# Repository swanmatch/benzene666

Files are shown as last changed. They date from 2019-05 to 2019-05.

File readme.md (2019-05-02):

# benzene666ビルドガイド

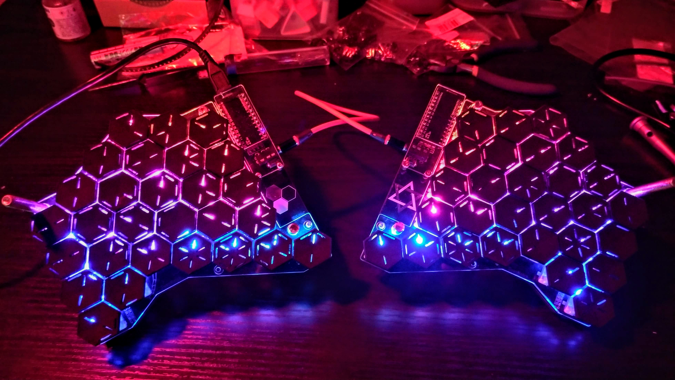
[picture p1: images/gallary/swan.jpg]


## 材料

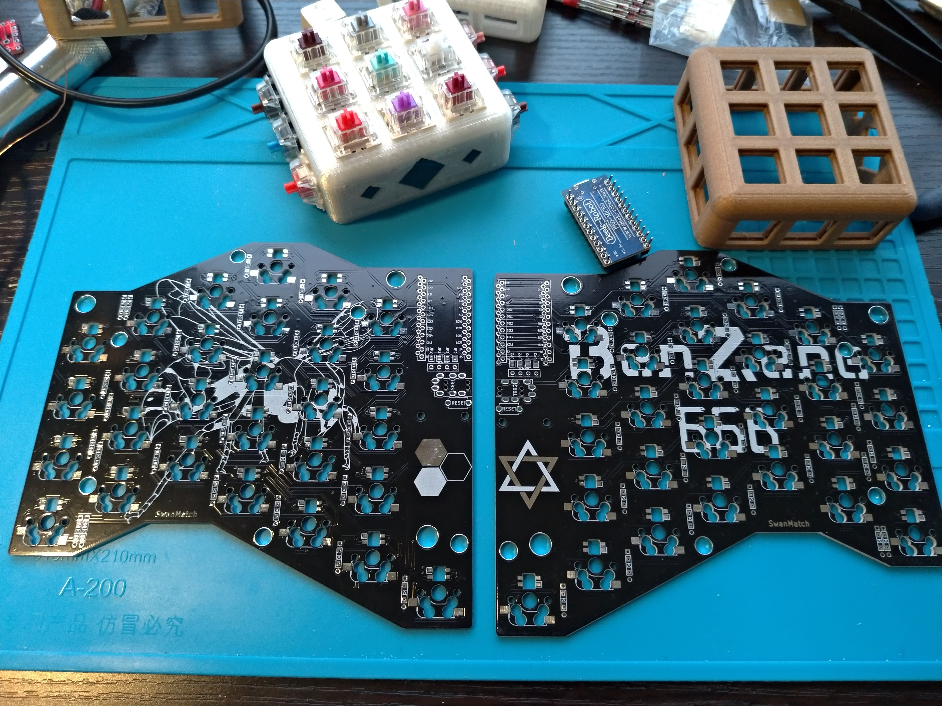
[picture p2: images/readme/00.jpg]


### キットに含まれるもの

| 品目 | 数量 |
| --- | ---- |
| PCB | 2枚  |
| トッププレート | 2枚  |
| ボトムプレート | 2枚  |
| OLED保護プレート | 2枚  |
| ProMicro | 2個  |
| ダイオード | 56個 |
| LED | 56個 |
| Kailhソケット | 56個 |
| M24mmネジ | 28本 |
| 7mm六角スペーサ  | 12本 |
| 8mm丸スペーサ | 4本  |
| 低頭ネジ | 4本  |
| ゴム足 | 10本 |

### キット以外で必要なもの
| 品目 | 数量 |
| --- | ---- |
| スイッチ | 56個 |
| キーキャップ | 56個 |
| TRRSまたはTRSケーブル | 1本  |
| USBケーブル | 1本  |

### オプション品

| 品目 | 数量 |
| --- | ---- |
| コンスルー | 4本  |
| M6ボルト | 6本  |
| M6ナット | 6個  |
| *)OLED | 2個  |

OLEDは動作未検証です。

## 組み立て手順

### LED

LEDをはんだ付けします。

シルクで白く囲ってあるのが一番大きいパッドです。

温度調整はんだごてで220度くらいに設定してください。もたついてると壊れます。

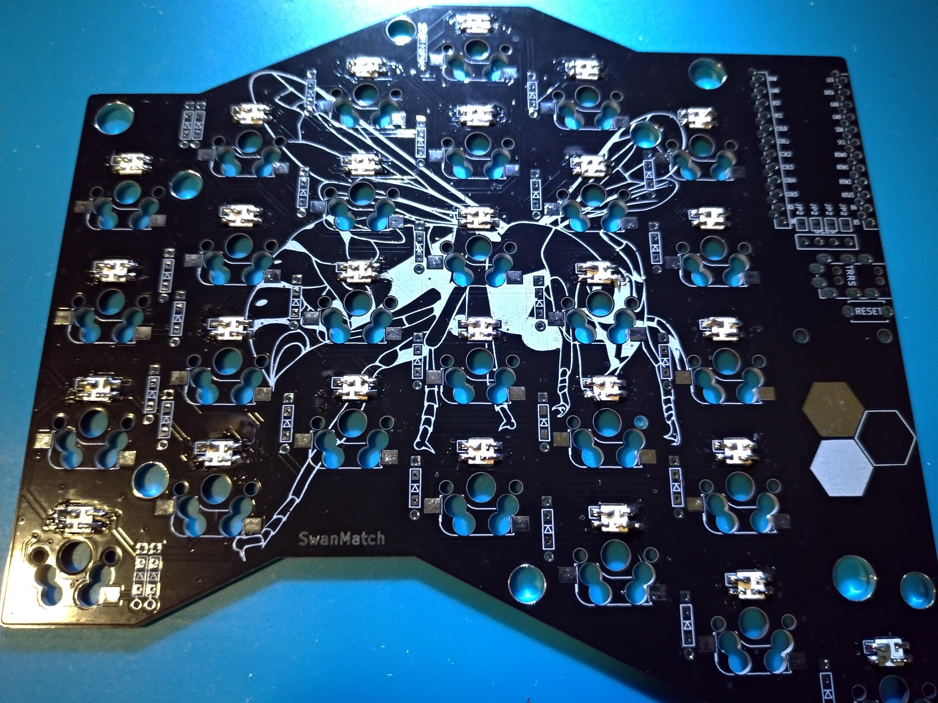
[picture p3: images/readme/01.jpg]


### ダイオード

ダイオードをはんだ付けしてください。向きに気をつけてください。

スルーホールの場合は黒が上、表面実装の場合うっすら線が書いてあるほうが上です。

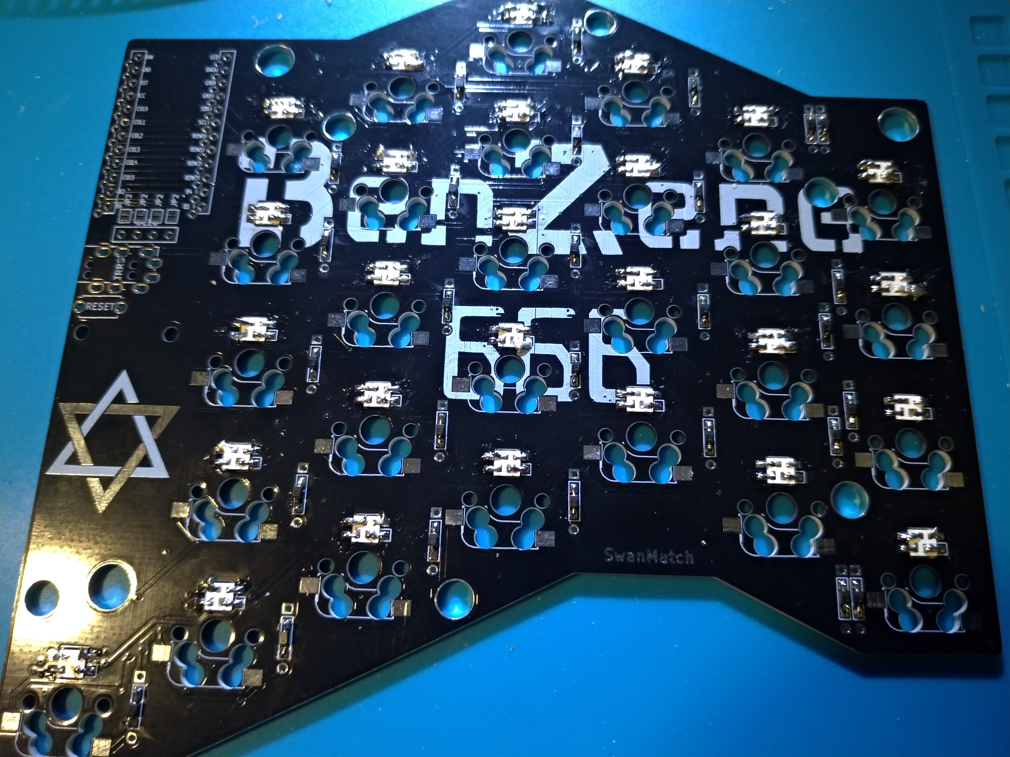
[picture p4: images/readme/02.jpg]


### ソケット

ソケットをはんだ付けしてください。

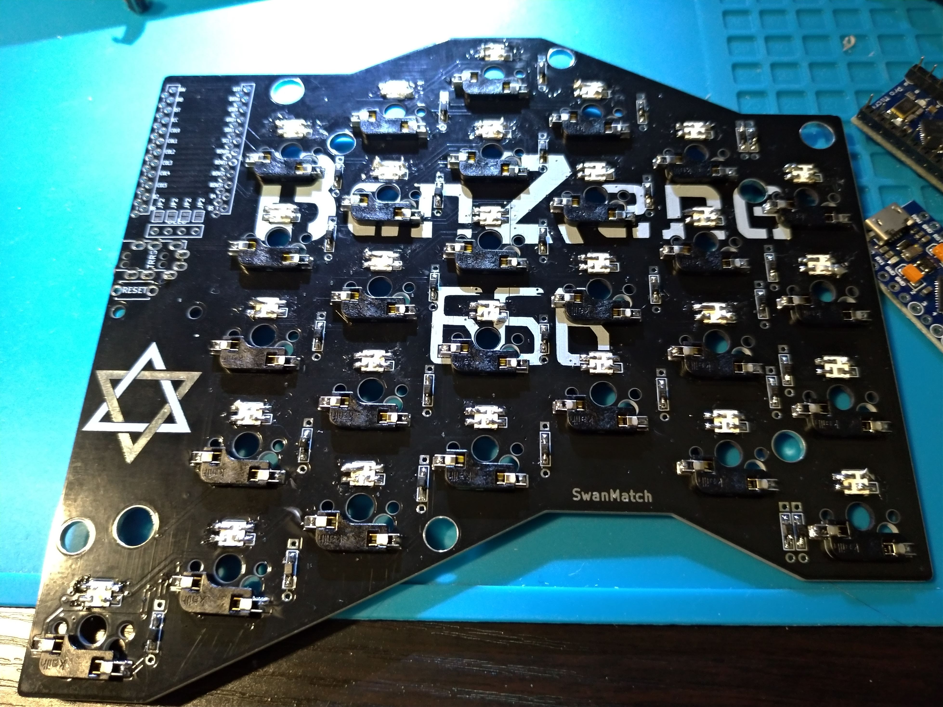
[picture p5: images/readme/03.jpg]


### TRRS、リセットスイッチ

はんだ付けしてください。

### ProMicro

ここだけは間違えるとリカバリが面倒なので、細心の注意をして作業にあたってください。

コンスルーを使う場合はHelixなどのビルドガイドを参考にしてください。

四角く囲ってあるところに付属のピンを指して裏からはんだ付けして、表面にProMicroを指してはんだ付けしてください。

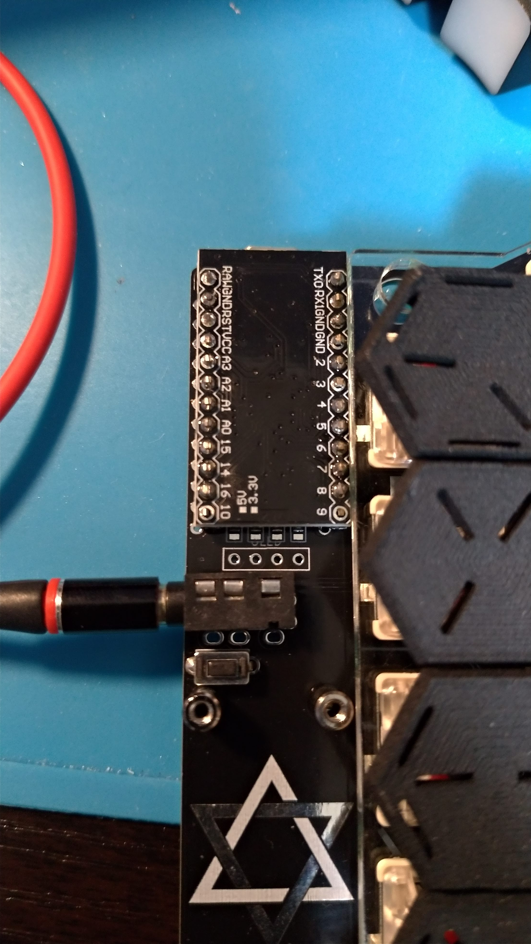
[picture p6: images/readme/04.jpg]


### スイッチ

トッププレートにスイッチをはめて、PCBに刺します。

このときすべてのピンが真っすぐになっていることを確認してください。

ピンが折れてしまいます。

### OLED保護プレート

PCB裏側から丸スペーサーをネジ止めして、表側に保護プレートを挟み込む形で低頭ネジでとめます。

### プレート

六角スペーサーとネジでPCBをサンドします。

ボトムプレートにゴム足を貼り付けてください。

反対側も同様に組み立てます。

### ファームウェア

```sh
git clone https://github.com/swanmatch/qmk_firmware.git
cd qmk_firmware
make benzene:swan:avrdude
```

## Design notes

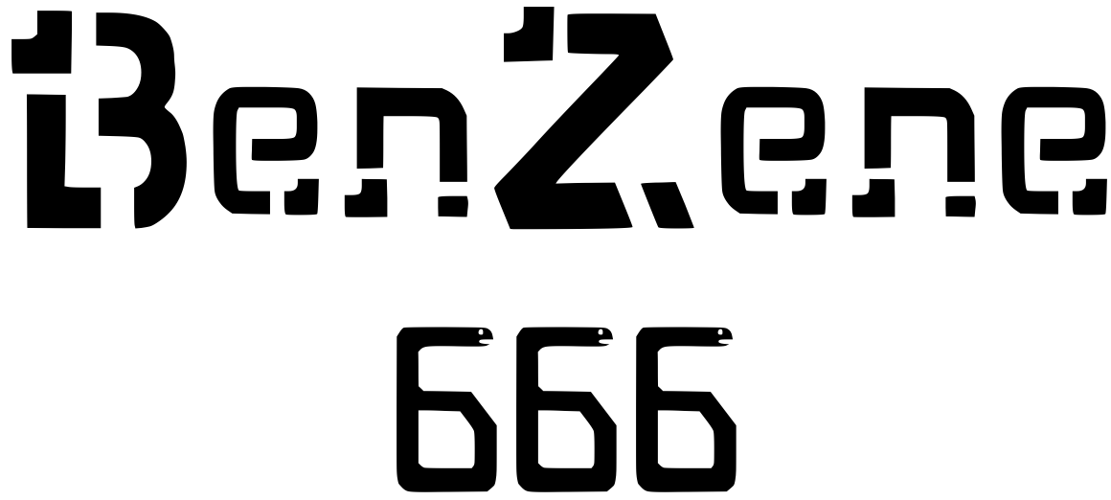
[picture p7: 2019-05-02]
case/benzene.png

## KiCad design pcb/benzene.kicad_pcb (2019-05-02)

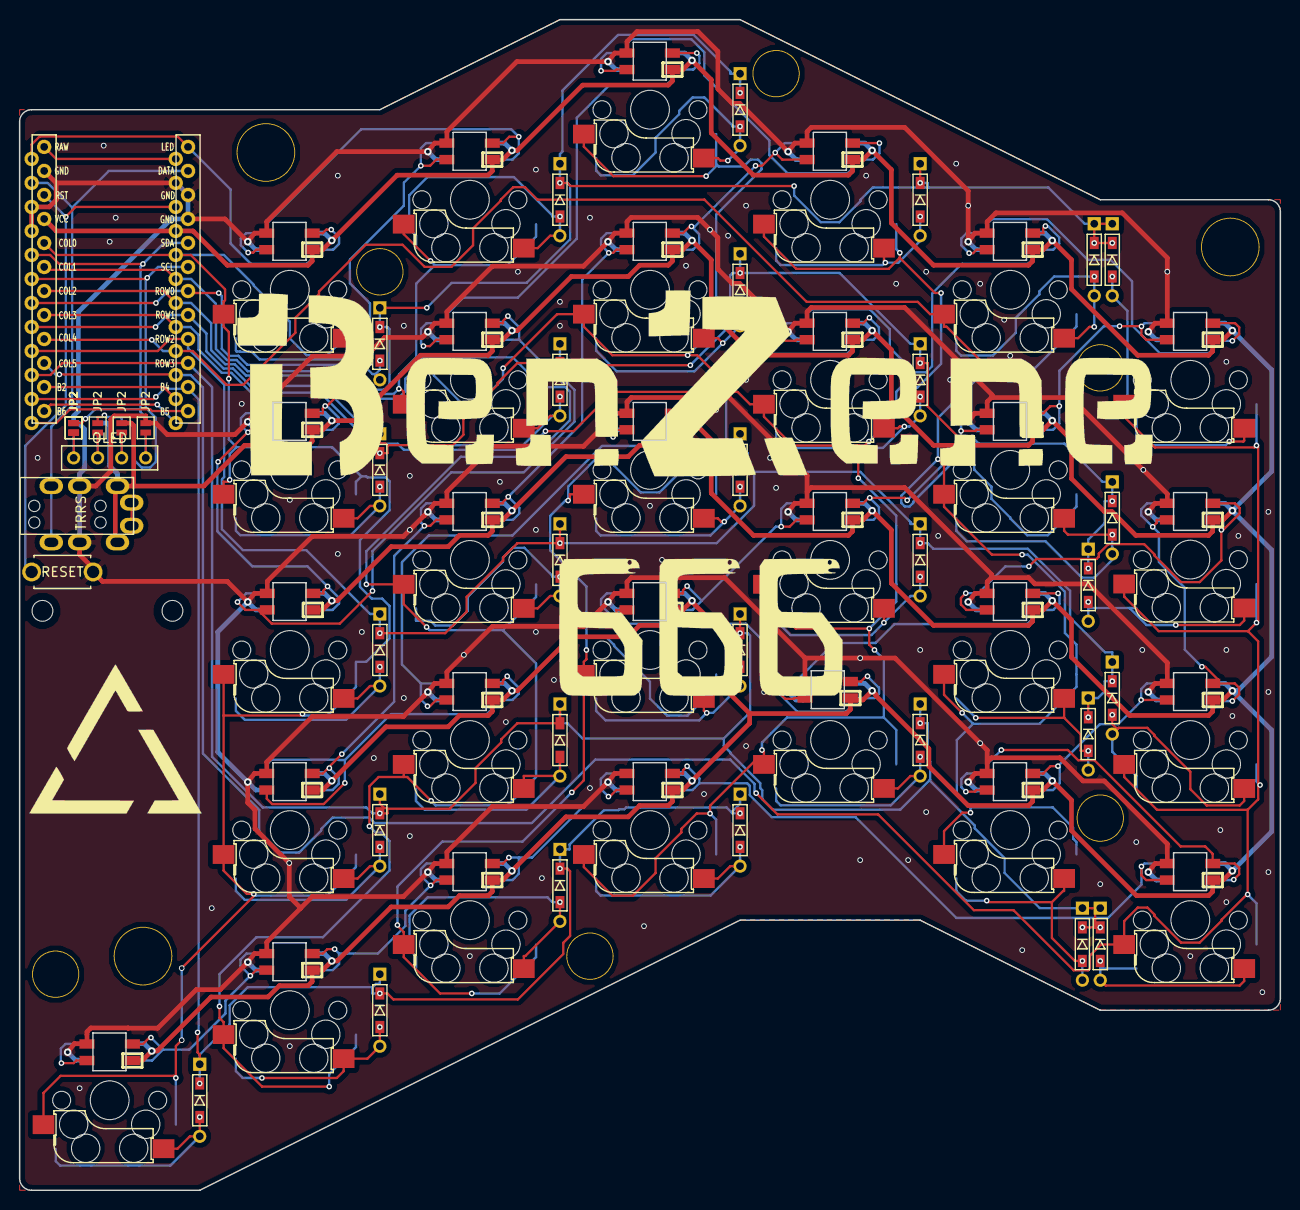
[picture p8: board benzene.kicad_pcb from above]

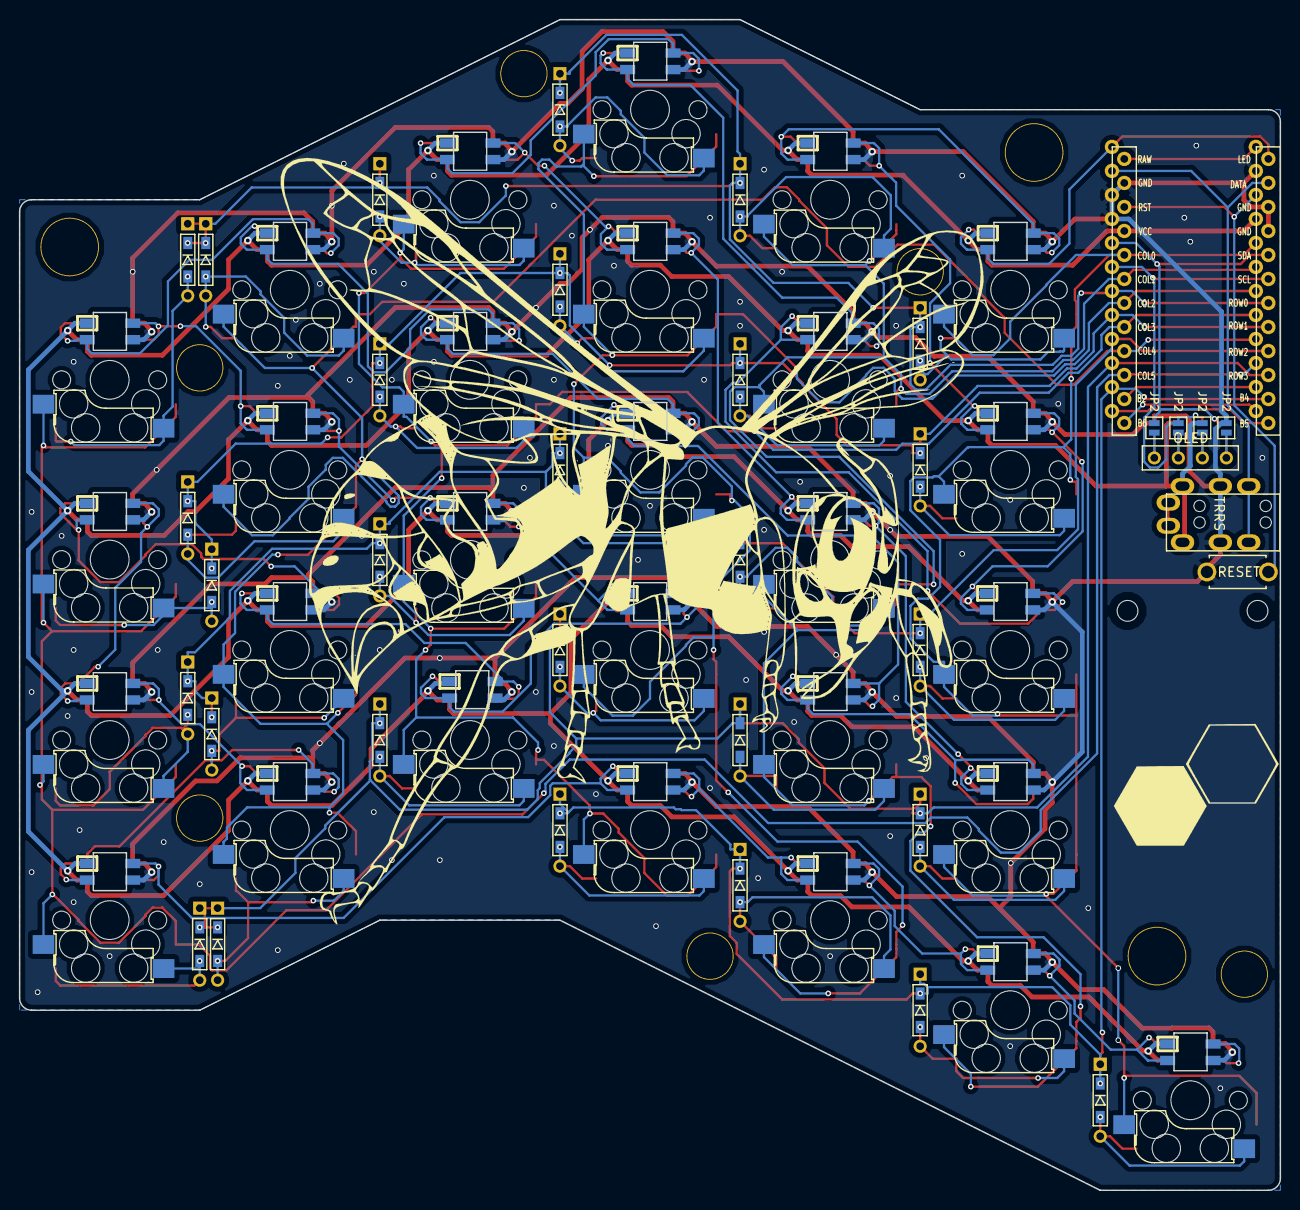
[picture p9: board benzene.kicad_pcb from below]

Board: 2 copper layers, 133.4 x 123.8 mm, 110 parts (6 on the bottom side), 77 nets.

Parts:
D1, D2, D3, D4, D5, D6, D7, D8, D9, D10, D11, D12, D13, D14, D15, D16, D17, D18, D19, D20, D21, D22, D23, D24, D25, D26, D27, D28: D; D3_TH_SMD
G1: LOGO; hxa_msk
G2: LOGO; hxa_slk
HOLE_M2_0, HOLE_M2_1: VAL**; HOLE_M2
J1: MJ-4PP-9
J2, J3, J4, J5, J6, J7, J8, J9, J10: JP2; Jumper
L1, L2, L3, L4, L5, L6, L7, L8, L9, L10, L11, L12, L13, L14, L15, L16, L17, L18, L19, L20, L21, L22, L23, L24, L25, L26, L27, L28: SK6812MINI; SK6812MINI_rev
OLED1: OLED
RESET1: SW_PUSH; ResetSW
Ref0, Ref1, Ref2, Ref3, Ref4, Ref5, Ref6, Ref7, Ref8: Val**; HOLE
SW1, SW2, SW3, SW4, SW5, SW6, SW7, SW8, SW9, SW10, SW11, SW12, SW13, SW14, SW15, SW16, SW17, SW18, SW19, SW20, SW21, SW22, SW23, SW24, SW25, SW26, SW27, SW28: SW_PUSH; CherryMX_Hotswap_outline
U1: ProMicro; ProMicro_v2

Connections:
DATA: J1.B, U1.2
GND: J1.C, J2.1, J10.1, L1.2, L2.2, L3.2, L4.2, L5.2, L6.2, L7.2, L8.2, L9.2, L10.2, L11.2, L12.2, L13.2, L14.2, L15.2, L16.2, L17.2, L18.2, L19.2, L20.2, L21.2, L22.2, L23.2, L24.2, L25.2, L26.2, L27.2, L28.2, RESET1.2, U1.3, U1.4, U1.23
LED: L1.3, U1.1
unnamed: D1.2, SW1.2
unnamed: D2.2, SW2.2
unnamed: D3.2, SW3.2
unnamed: D4.2, SW4.2
unnamed: D5.2, SW5.2
unnamed: D6.2, SW6.2
unnamed: D7.2, SW7.2
unnamed: D8.2, SW8.2
unnamed: D9.2, SW9.2
unnamed: D10.2, SW10.2
unnamed: D11.2, SW11.2
unnamed: D12.2, SW12.2
unnamed: D13.2, SW13.2
unnamed: D14.2, SW14.2
unnamed: D15.2, SW15.2
unnamed: D16.2, SW16.2
unnamed: D17.2, SW17.2
unnamed: D18.2, SW18.2
unnamed: D19.2, SW19.2
unnamed: D20.2, SW20.2
unnamed: D21.2, SW21.2
unnamed: D22.2, SW22.2
unnamed: D23.2, SW23.2
unnamed: D24.2, SW24.2
unnamed: D25.2, SW25.2
unnamed: D26.2, SW26.2
unnamed: D27.2, SW27.2
unnamed: D28.2, SW28.2
unnamed: J2.2, J7.2, OLED1.4
unnamed: J4.2, J8.2, OLED1.3
unnamed: J5.2, J9.2, OLED1.2
unnamed: J3.2, J6.2, J10.2, OLED1.1
unnamed: L1.1, L2.3
unnamed: L2.1, L7.3
unnamed: L3.1, L4.3
unnamed: L3.3, L8.1
unnamed: L4.1, L9.3
unnamed: L5.1, L6.3
unnamed: L5.3, L10.1
unnamed: L10.3, L15.1
unnamed: L11.1, L16.3
unnamed: L6.1, L11.3
unnamed: L12.1, L18.3
unnamed: L12.3, L17.1
unnamed: L8.3, L13.1
unnamed: L7.1, L13.3
unnamed: L14.1, L19.3
unnamed: L9.1, L14.3
unnamed: L15.3, L20.1
unnamed: L16.1, L21.3
unnamed: L17.3, L22.1
unnamed: L18.1, L23.3
unnamed: L19.1, L20.3
unnamed: L21.1, L22.3
unnamed: L23.1, L24.3
unnamed: L24.1, L28.3
unnamed: L25.3, L26.1
unnamed: L26.3, L27.1
unnamed: L27.3, L28.1
RST: RESET1.1, U1.22
SCL: J5.1, J8.1, U1.6
SDA: J3.1, J6.1, J7.1, U1.5
VCC: J1.D, J4.1, J9.1, L1.4, L2.4, L3.4, L4.4, L5.4, L6.4, L7.4, L8.4, L9.4, L10.4, L11.4, L12.4, L13.4, L14.4, L15.4, L16.4, L17.4, L18.4, L19.4, L20.4, L21.4, L22.4, L23.4, L24.4, L25.4, L26.4, L27.4, L28.4, U1.21
col0: SW1.1, SW7.1, SW13.1, SW19.1, SW25.1, U1.20
col1: SW2.1, SW8.1, SW14.1, SW20.1, SW26.1, U1.19
col2: SW3.1, SW9.1, SW15.1, SW21.1, SW27.1, U1.18
col3: SW4.1, SW10.1, SW16.1, SW22.1, SW28.1, U1.17
col4: SW5.1, SW11.1, SW17.1, SW23.1, U1.16
col5: SW6.1, SW12.1, SW18.1, SW24.1, U1.15
row0: D1.1, D2.1, D3.1, D4.1, D5.1, D6.1, U1.7
row1: D7.1, D8.1, D9.1, D10.1, D11.1, D12.1, U1.8
row2: D13.1, D14.1, D15.1, D16.1, D17.1, D18.1, U1.9
row3: D19.1, D20.1, D21.1, D22.1, D23.1, D24.1, U1.10
row4: D25.1, D26.1, D27.1, D28.1, U1.11
